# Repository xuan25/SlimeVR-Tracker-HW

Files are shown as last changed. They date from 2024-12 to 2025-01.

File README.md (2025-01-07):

# SlimeVR-Tracker-HW by Xuan25

A design of SlimeVR Tracker by Xuan25

- PCB: PCB designed with KiCAD 8.0.7
- Case: Case designed with FreeCAD 1.0.0
- Adapted firmware is available [here](https://github.com/xuan25/SlimeVR-Tracker-ESP)

## Features

- IMU: BNO085; MCU: ESP32-C3
- 3D printed case
- 2-layer PCB
- firmware uploading via USB
- 9-hour durability with 700mAh 803030 Li-Po battery
- Dimension: 57mm (l) x 37mm (w) x 23mm (h)
- Optimized for hand soldering (hot plate required), with enough spacing to comfortably handle 0603 SMD components and maintain adequate clearance.

## Preview


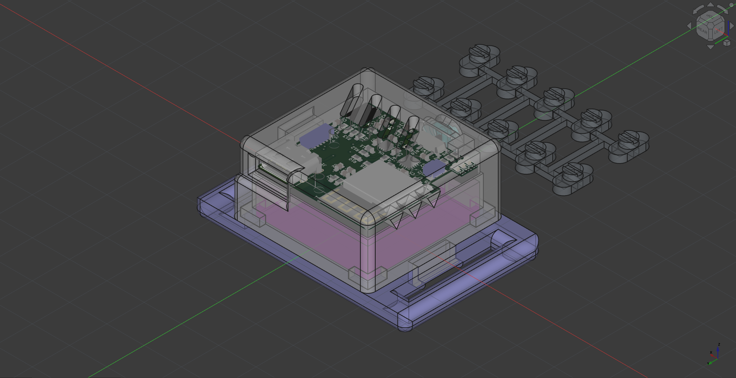
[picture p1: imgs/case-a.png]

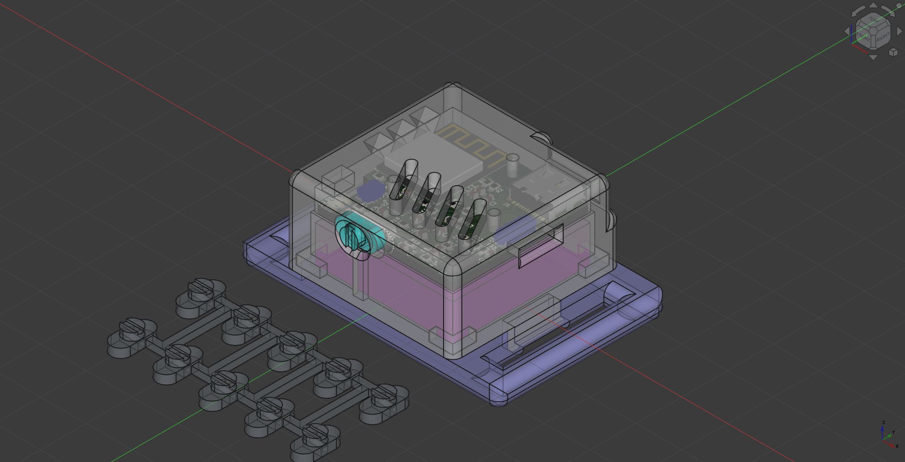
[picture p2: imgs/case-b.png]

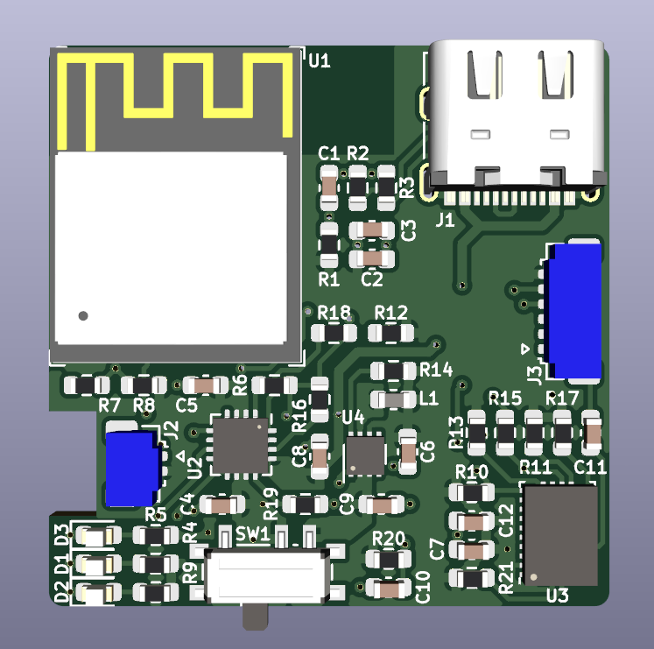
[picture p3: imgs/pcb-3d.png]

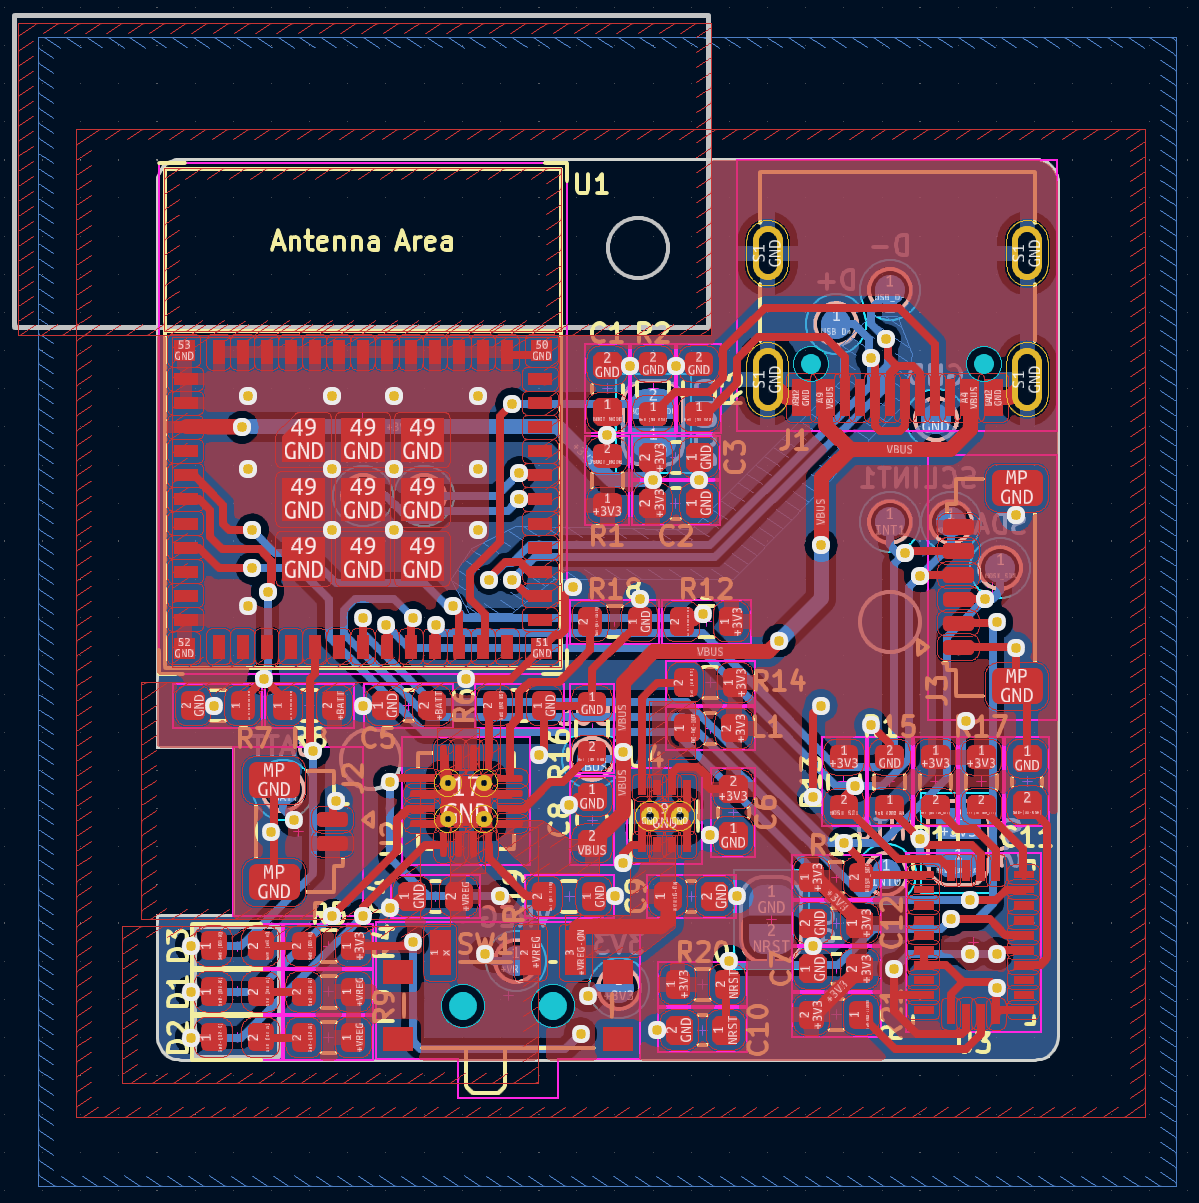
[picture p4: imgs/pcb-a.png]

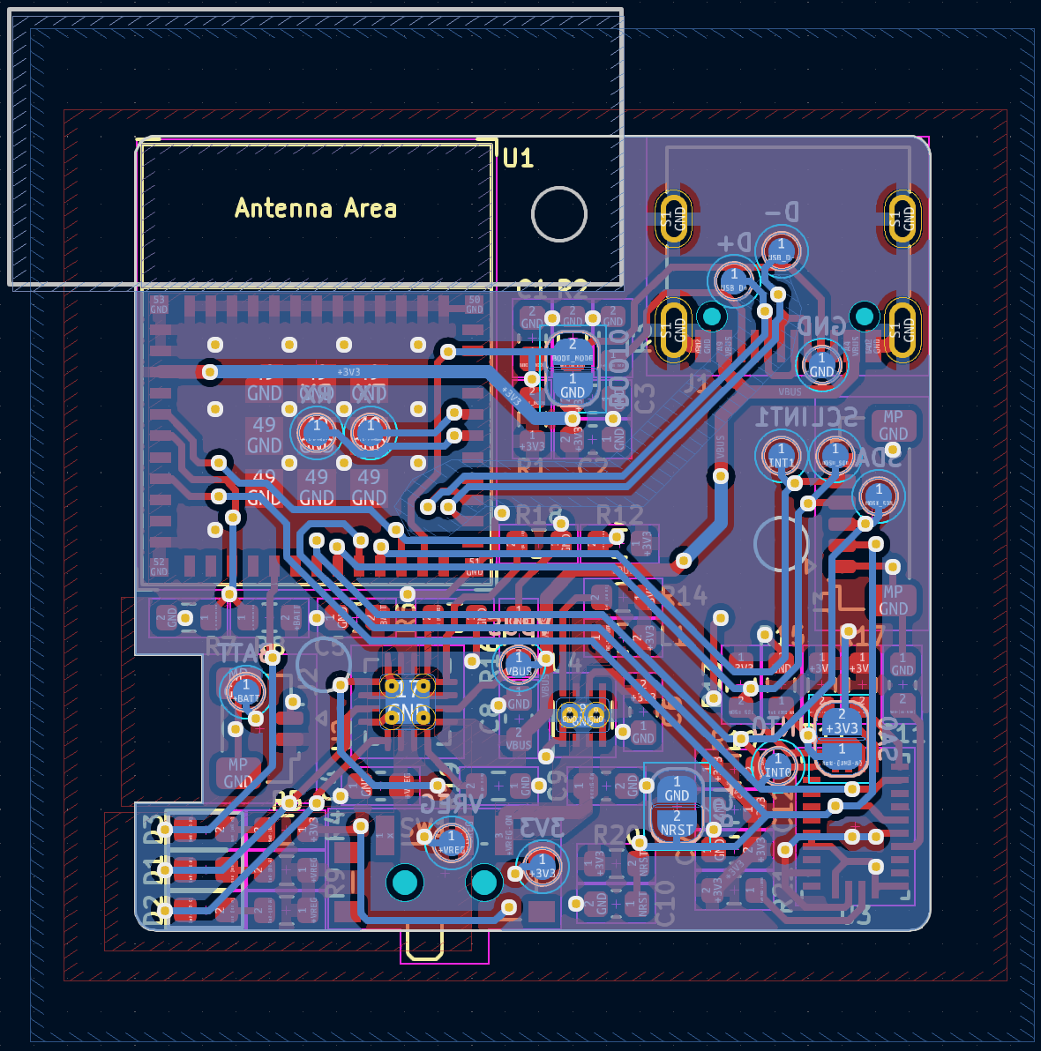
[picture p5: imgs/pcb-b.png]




## Production Resources

### Files

See the [latest release](https://github.com/xuan25/SlimeVR-Tracker-HW/releases/latest) for the production files:

- `PCB-gbr.zip`: Gerber files for PCB production  
- `PCB-BOM.csv`: Bill of Materials for PCB assembly  
- `PCB-assembly-scale4.pdf`: Component reference for PCB assembly  
- `3DP.zip`: STL model files for 3D printing  

### Assembly

In addition to the materials listed in the BOM for PCB assembly, you will also need:

- `700mAh 803030 3.7V Lithium Polymer Battery` x1 (the battery)
- `SSUH-003T-P0.15` x2 (socket contacts for the battery)
- `SUHR-02V-S-B` x1 (socket contact housing)
- `28AWG FEP Wire` x2 (wires connect the battery and the PCB)
- `2mm thick EVA Foam Craft Sheets` x1 (spacer between the battery and the PCB)
- `25mm width Elastic Band` + `Accessories`

plus:

- `138°C Low Temperature Soldering Paste`
- `Solder Flux`
- `PCB Cleaning Solution` + `Brush`
- `8mm Polyimide Tape` + `30mm Polyimide Tape` (for battery breakout board insulation)

Required tools include:

- `ENGINEER PAD-11 Handy Crimp Tool` (crimp battery connectors)
- `Hotplate for SMD Soldering`
- `Soldering Iron`
- `Tweezers`
- `Diagonal cutting plier` + `Sandpaper` (3D printing post-processing)
- (Optional) `Light and Magnifier`

## Please note: Before you send the case model to your 3D printer

**You may want to update the following parameters in the Case design Spreadsheet to match the performance of your 3D printer and material.**

- **Tol**: Adjusts the clearance between mating parts. Increase this value if your 3D printer cannot achieve tight tolerances, ensuring the parts fit together properly despite limited printing accuracy.
- **SnapFitNotchWidth**: Controls the depth of the snap-fit notch. A larger value can provide a more robust snap-fit connection but requires the material to have better toughness.
  - Plastics are usually stronger than resin, so you should consider to use a lower value.
- **BaseMargin**: Controls the margin of the base. Since the snap-fit will catch on the base’s margin, a smaller margin requires the material to have sufficient strength to ensure a reliable snap-fit connection.
  - Resin are usually softer than plastics, so you should consider to use a greater value.

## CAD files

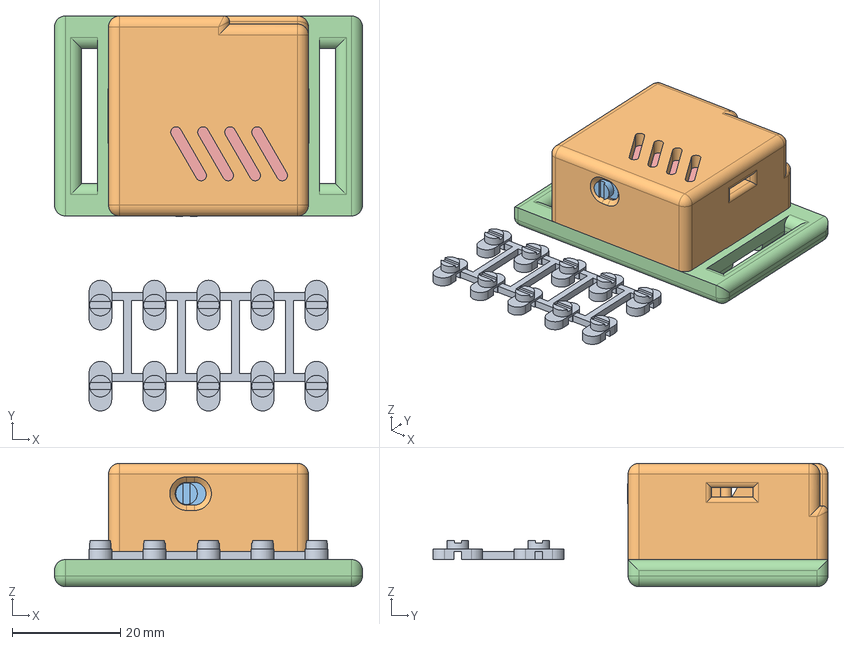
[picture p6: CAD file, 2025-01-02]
Case/SlimeVRTracker.FCStd
57.0 x 73.1 x 22.8 mm
Cover
Switch
Base
Batt

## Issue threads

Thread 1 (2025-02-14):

Would it be possible to support more IMU, such as BMI ？

TinyOra, 2025-02-14:
Your solution is excellent, and I’m considering adopting it. However, the 085 isn't the best choice anymore these days, is it?

TinyOra, 2025-04-25:
Hello, I am trying to follow your plan, but I encountered some issues while flashing the firmware. When uploading the firmware in VSCODE, I received a message stating that the port could not be opened. While using the flash_download_tool to upload the firmware, I got the following error message: "Could not open COM9, the port is busy or doesn't exist. (Cannot configure port, something went wrong. Original message: PermissionError(13, 'The device attached to the system is not functioning.', None, 31))."

TinyOra, 2025-04-25:
Problem solved , but i got a new issue, when connected via USB, the battery was not charged, although other functions are normal. I'm not sure what the reason is.

xuan25, 2025-04-25:
Hi @TinyOra ,

Glad to hear you have the previous problem sorted.

Have you checked whether it is an LED indicator issue or a charging issue? If you disconnect the battery and plug in the external power source via USB, the charging LED (RED) should blink once rapidly and then turn off, while the power LED (GREEN) should remain on.

Both LEDs are connected to the battery charging IC (U2). If this behavior is not happening, there could be an issue with your battery charging circuit or the CC resistors of the USB receptacle.

Here are the related schematics:

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

TinyOra, 2025-04-27:
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

@xuan25   Thanks for your help. The LED behavior matches what you described, so I think the issue must be with the charging circuit. I noticed that the chip I purchased is labeled BQ24075RGTR, which has an extra 'R' compared to your model. Could that be the cause of the problem?"

TinyOra, 2025-05-05:
> > I noticed that the chip I purchased is labeled BQ24075RGTR, which has an extra 'R' compared to your model. Could that be the cause of the problem?"
>
> The last "R" is for Tape and Reel Packaging which should not have any influence on the chip itself.

Hi @xuan25

As u said, If i disconnect the battery and plug in the external power , the Red LED blink once rapidly and then turn off, but if i connect battery, the red led remain on.

However, when I checked with USB current meter, the battery was not charging

I made several units, and they all exhibit the same issue. All other functions are working , even the IMU can be recognized by the SlimeVR server via USB

I'm very confused. I've checked almost every pin and noticed that the TS pin remains at 0V at all times. According to the datasheet, this pin shouldn't be at 0V when connected to a 10kΩ resistor—otherwise charging will be disabled. I suspect this might be the root cause

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

xuan25, 2025-05-06:
Hi @TinyOra ,

>I'm very confused. I've checked almost every pin and noticed that the TS pin remains at 0V at all times. According to the datasheet, this pin shouldn't be at 0V when connected to a 10kΩ resistor—otherwise charging will be disabled. I suspect this might be the root cause

0 V on the TS pin is weird.

In my case, the TS voltage (measured at the left pad of R6) is typically around 0.75 V, as shown in the photo.

Hope this will help.

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

xuan25, 2025-06-14:
Hi @TinyOra,

Glad to hear you’ve got the problem sorted.

Sure, all my design files are available as the `source code` of this repository. Specifically, you can find the PCB design in the `PCB` folder, which you can open with [KiCAD](https://www.kicad.org/). The project includes both the schematic and the PCB layout. You may want to focus the 6th page (Sensor) of the schematic for IMU adaptation. In addition, the case design is available in the `Case` folder and can be opened with [FreeCAD](https://www.freecad.org/).

Please let me know if you have any further questions.

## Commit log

2024-12-19 Init repo
    [SlimeVR-Tracker.kicad_pcb, SlimeVR-Tracker.kicad_sch, SlimeVRTracker.FCStd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]
2024-12-21 Add teardrops on PCB
    [SlimeVR-Tracker.kicad_pcb]
2024-12-21 Fix broken faces on the 3D design of the switch
    [SlimeVRTracker.FCStd]
2025-01-02 Adjust SnapFitNotchWidth, Add extra width to SnapFitHole
    [SlimeVRTracker.FCStd]
2025-01-05 Adjust fonts on PCB Fab layers
    [SlimeVR-Tracker.kicad_pcb]
2025-01-05 Add missing tools and materials
2025-01-07 Migrate KiCad to version 8.0
    [SlimeVR-Tracker.kicad_pcb, SlimeVR-Tracker.kicad_sch, control.kicad_sch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]
